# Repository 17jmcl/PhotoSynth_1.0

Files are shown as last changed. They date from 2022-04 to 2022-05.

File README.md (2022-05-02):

# PhotoSynth
 PhotoSynth: A synth using Biodata to modulate effects. 
 
Date Updated Last: 05/02/22

Julie McLaughlin 
Thesis Project for Temple University 
Advisor: Dr. Adam Vidiksis 

Description (What it does, technology used, challenges and future features)
A synth with a 12 note keyboard using Biodata to modulate effects. 

It uses Teensy 3.5, a custom PCB board made with Fusion 360 Autodesk, and Teensyduino IDE. 

How to use the project:
Download SCH,PCB,Gerber, and BOM and open with your preferred developement software (example: Autodesk Fusion 360). Open ino files with Teensyduino or Arduino IDE, adjust your settings, and compile/run the code. 

-------------------------------------------------------------------------------

Dependencies: 
TeensyDuino: PJRC derivative of Arduino 
PJRC Audio Tool: Audio Library (PJRC)
Bounce2: Debouncing library for Arduino 

Credits:
Based on BiodataSonificationBreadboardKit from Sam Cusumano electricityforprogress and Instruo Scion 
Thanks to the help of my family, friends, and collaborators. 

------------------------------------------------------------------------------

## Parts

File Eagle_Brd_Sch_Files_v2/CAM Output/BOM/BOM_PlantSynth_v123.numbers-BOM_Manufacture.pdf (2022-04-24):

### BOM_Manufacture

Qty | Device | Value | Description
1 CPAL-MICRO- | MF-003 | | Power Cable with Button
6 | OEJL-75-2-5 | 3 20mm, 3 7mm (Approx) | Knob Caps
2 Max | Filament | | Choice between PLA, ABS, PETG, PA Nylon, Resin, Nylon Powder
6 Various Reused | Parts | | Parts found from broken electronics
1 | Snap Electrodes | | Pack of snap electrodes to 3.5mm male
1 Snap Electrode | Pads | | Pack of snap electrode pads
10000 | Plants | | Maybe not 10000 but make sure to name them

1

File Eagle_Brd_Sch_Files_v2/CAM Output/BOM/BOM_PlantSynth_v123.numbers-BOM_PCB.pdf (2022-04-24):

### Electronics Design:PlantSynth v123 BOM PCB

Qty | Device | Value | Schematic Labels | Description
2 | 3 Pin Header/ 16mm Knob | 3 pin | R13, R14 | 16mm pot from DHV B10K with B3B-XH-A 3 pin header
7 | B3F Omron Button | 6mm | S1, S2, S3, S4, S5, S6, S7 | OMRON SWITCH
8 | Green LED | Diffused | WP7113SGD1, WP7113SGD2, WP7113SGD3, WP7113SGD4, WP7113SGD5, WP7113SGD6, WP7113SGD7, WP7113SGD8 | WP7113SGD
1 | Capacitor | 0.1uF | C2 | CAPACITOR
1 | Resistor | 100k | R39 | RESISTOR
19 | Resistor | 10k | R1, R2, R3, R10, R11, R12, R15, R16, R17, R18, R19, R20, R21, R22, R23, R24, R25, R26, R40 | RESISTOR
8 | Resistor | 100ohm | R27, R28, R29, R30, R31, R32, R33, R34 | RESISTOR
1 | Capacitor | 4700pF | C1 | CAPACITOR
1 | Polarized Capacitor | 47uF | C3 | Capacitor Polarised
6 | Panasonic Knob | | R4, R5, R6, R7, R8, R9 | 9 mm Square Rotary Potentiometers
12 | FSR | FSR400 Series | FSR1, FSR2, FSR3, FSR4, FSR5, FSR6, FSR7, FSR8, FSR9, FSR10, FSR11, FSR12 | FSR400
1 | 555 Timer | LMC555CN | U3 | LMC555CN/NOPB-ND PDIP(8) TI 9.81x6.35mm
1 | 3.5mm Stereo Jack | Adafruit | STX-3120-5B-577C | STEREO JACK, Adafruit, Breadboard safe
1 | Teensy | Teensy 3.5 | U$1 | PJRC Teensy 3.5
1 | Teensy Audio Hat | SGTL5000 | | PJRC Audio hat (Optional)
1 | Teensy Header Set | 24,24,4 | | Teensy header set

1

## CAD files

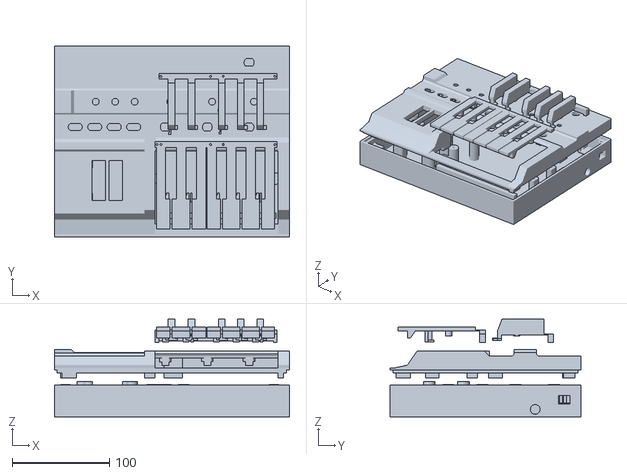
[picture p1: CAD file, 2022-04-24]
Fusion360_3D_Design_Files/Design1/PlantSynth_MainDesign_Full_STL.stl
241.3 x 195.8 x 100.4

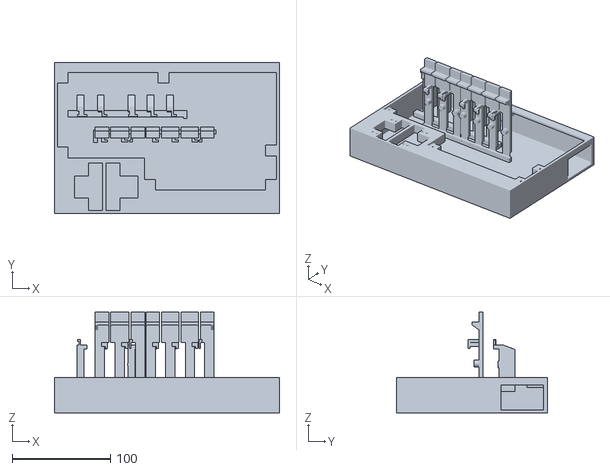
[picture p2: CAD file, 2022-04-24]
Fusion360_3D_Design_Files/Design2/Option2_Full_STL.stl
229.6 x 154.1 x 102.8

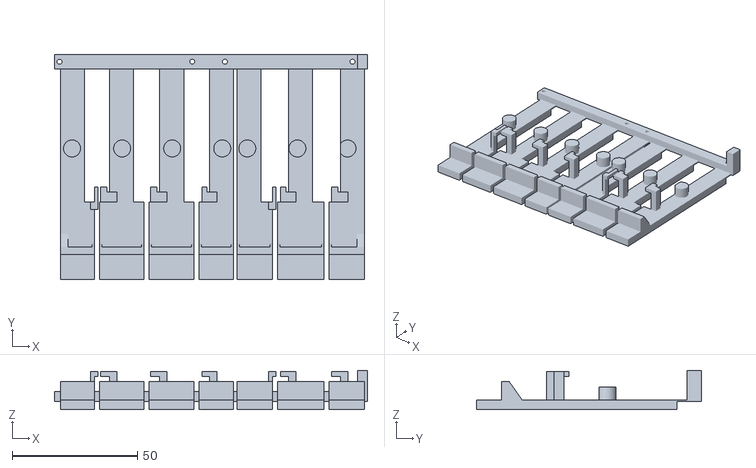
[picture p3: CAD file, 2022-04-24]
Fusion360_3D_Design_Files/Design1/3D_Export_Other/White Piano Keys_STL.stl
125.0 x 89.9 x 15.7

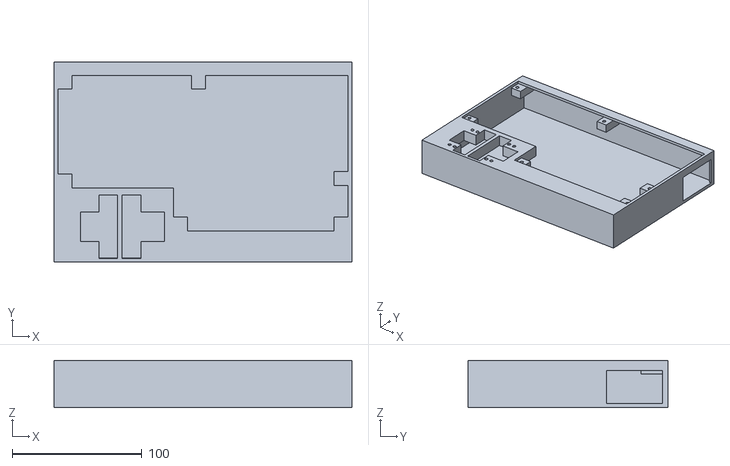
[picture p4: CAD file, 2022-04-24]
Fusion360_3D_Design_Files/Design2/Options2_3D_Export_Other/Option2_BODYonly_STL.stl
229.6 x 154.1 x 36.2

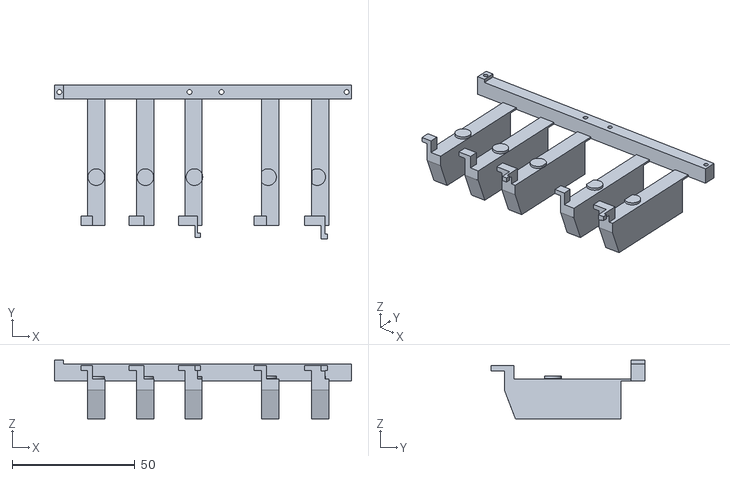
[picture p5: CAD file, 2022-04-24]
Fusion360_3D_Design_Files/Design1/3D_Export_Other/BlackKeys_STL.stl
121.0 x 62.7 x 23.9

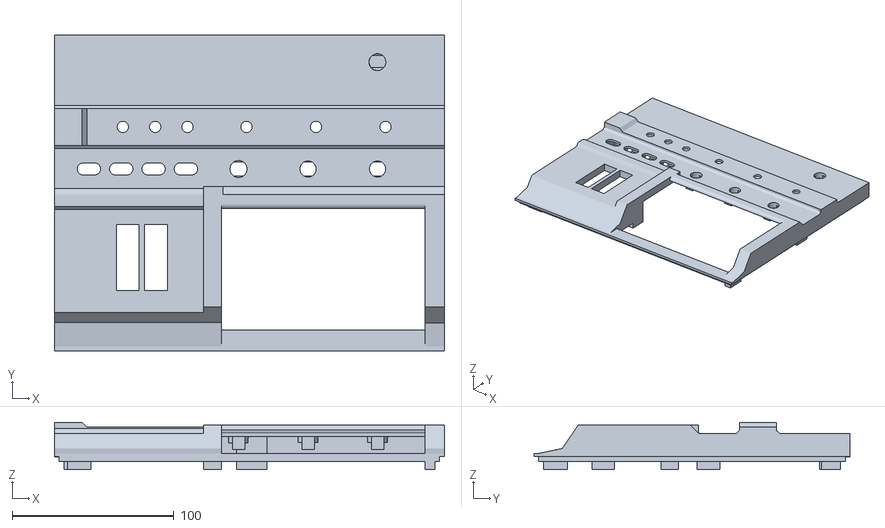
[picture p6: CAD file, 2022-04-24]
Fusion360_3D_Design_Files/Design1/3D_Export_Other/TopOnly_STL.stl
241.3 x 195.8 x 29.2

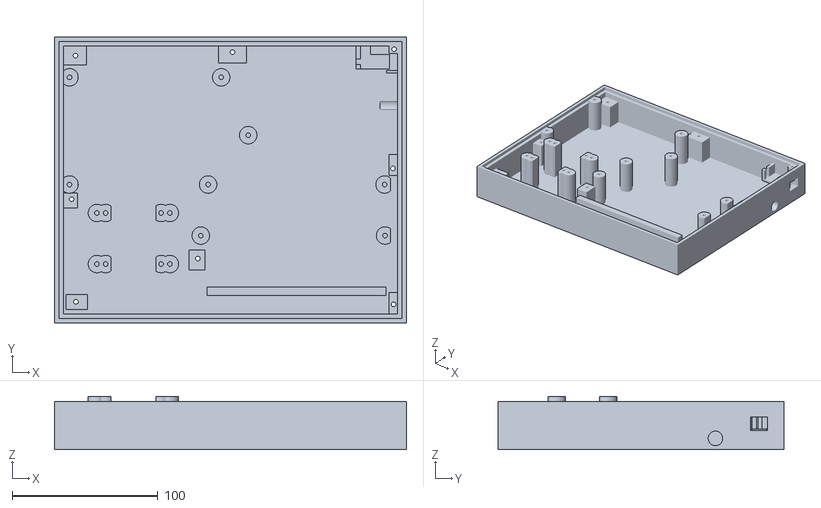
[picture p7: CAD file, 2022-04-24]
Fusion360_3D_Design_Files/Design1/3D_Export_Other/BottomOnly_STL.stl
241.3 x 195.8 x 36.5

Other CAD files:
Fusion360_3D_Design_Files/Design1/3D_Export_Other/PlantSynth_MainDesign_3MF.3mf
Fusion360_3D_Design_Files/Design1/3D_Export_Other/PlantSynth_MainDesign_OBJ.obj
Fusion360_3D_Design_Files/Design2/Options2_3D_Export_Other/Option2_ASCII.stl
Fusion360_3D_Design_Files/Design2/Options2_3D_Export_Other/Option2_3MF.3mf
Fusion360_3D_Design_Files/Design2/Options2_3D_Export_Other/Option2_OBJ.obj
Eagle_Brd_Sch_Files_v2/Electronics Design_PlantSynth_v131.f3z

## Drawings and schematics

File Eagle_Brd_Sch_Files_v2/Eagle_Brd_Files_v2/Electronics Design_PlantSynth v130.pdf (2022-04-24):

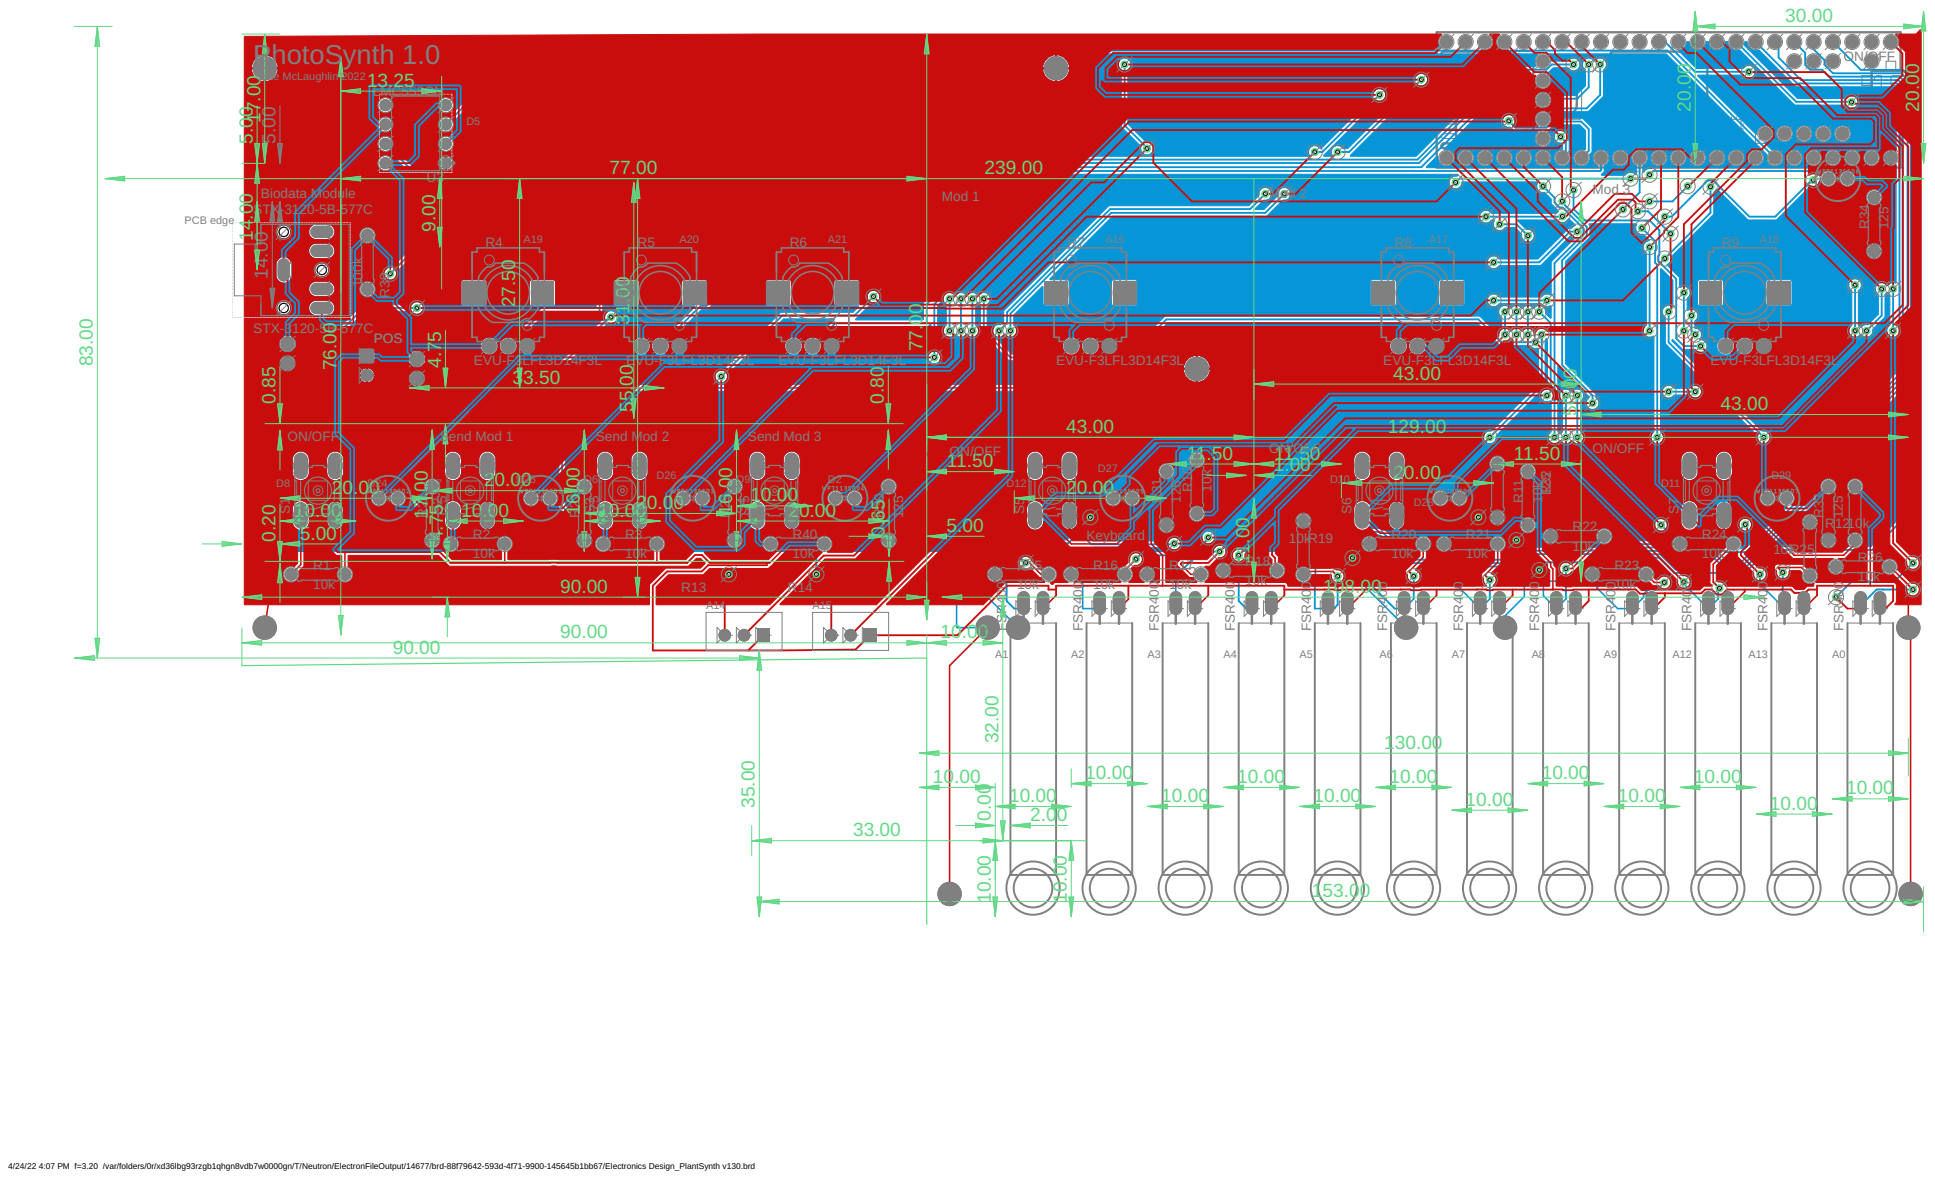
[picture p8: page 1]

4/24/22 4:07 PM f=3.20 /var/folders/0r/xd36lbg93rzgb1qhgn8vdb7w0000gn/T/Neutron/ElectronFileOutput/14677/brd-88f79642-593d-4f71-9900-145645b1bb67/Electronics Design_PlantSynth v130.brd

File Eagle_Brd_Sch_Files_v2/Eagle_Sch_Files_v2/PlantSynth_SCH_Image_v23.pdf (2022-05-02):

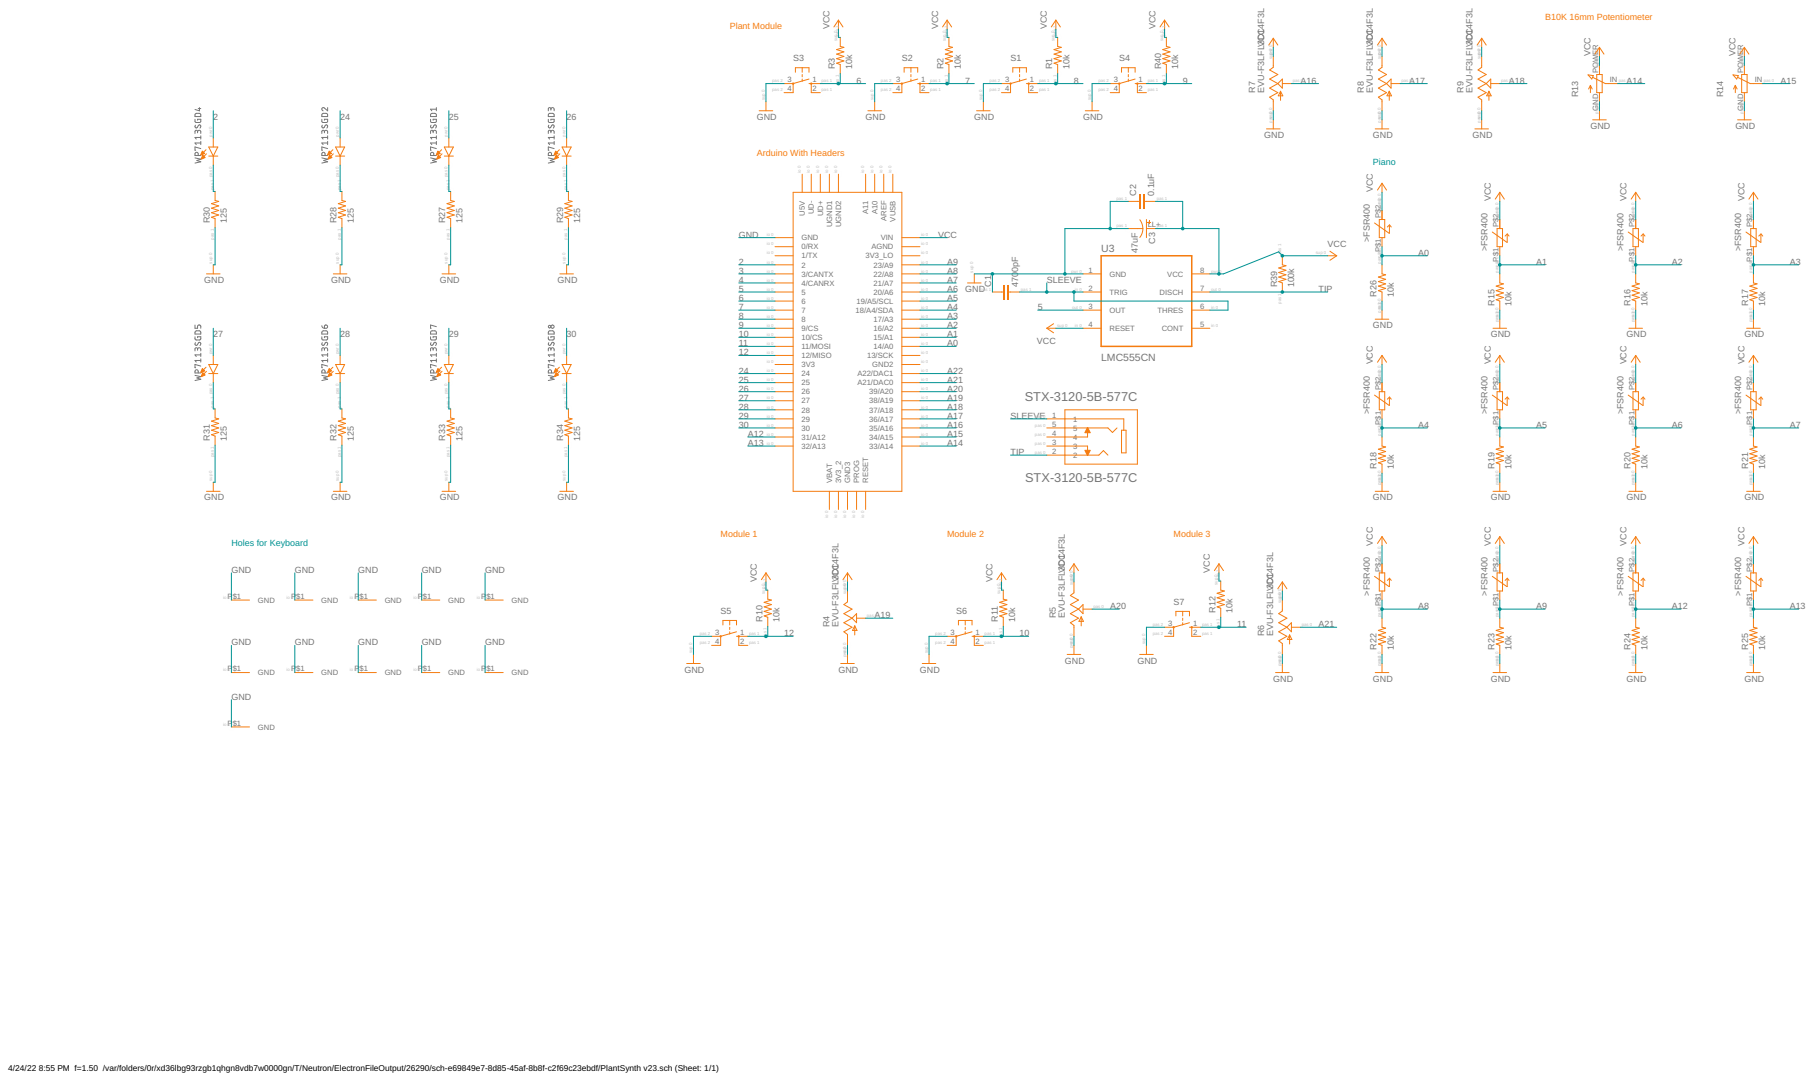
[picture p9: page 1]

pas 1 pas 1 out 0 pwr 0 sup 0 sup 0

out 0 pwr 0 sup 0 sup 0

4/24/22 8:55 PM f=1.50 /var/folders/0r/xd36lbg93rzgb1qhgn8vdb7w0000gn/T/Neutron/ElectronFileOutput/26290/sch-e69849e7-8d85-45af-8b8f-c2f69c23ebdf/PlantSynth v23.sch (Sheet: 1/1)

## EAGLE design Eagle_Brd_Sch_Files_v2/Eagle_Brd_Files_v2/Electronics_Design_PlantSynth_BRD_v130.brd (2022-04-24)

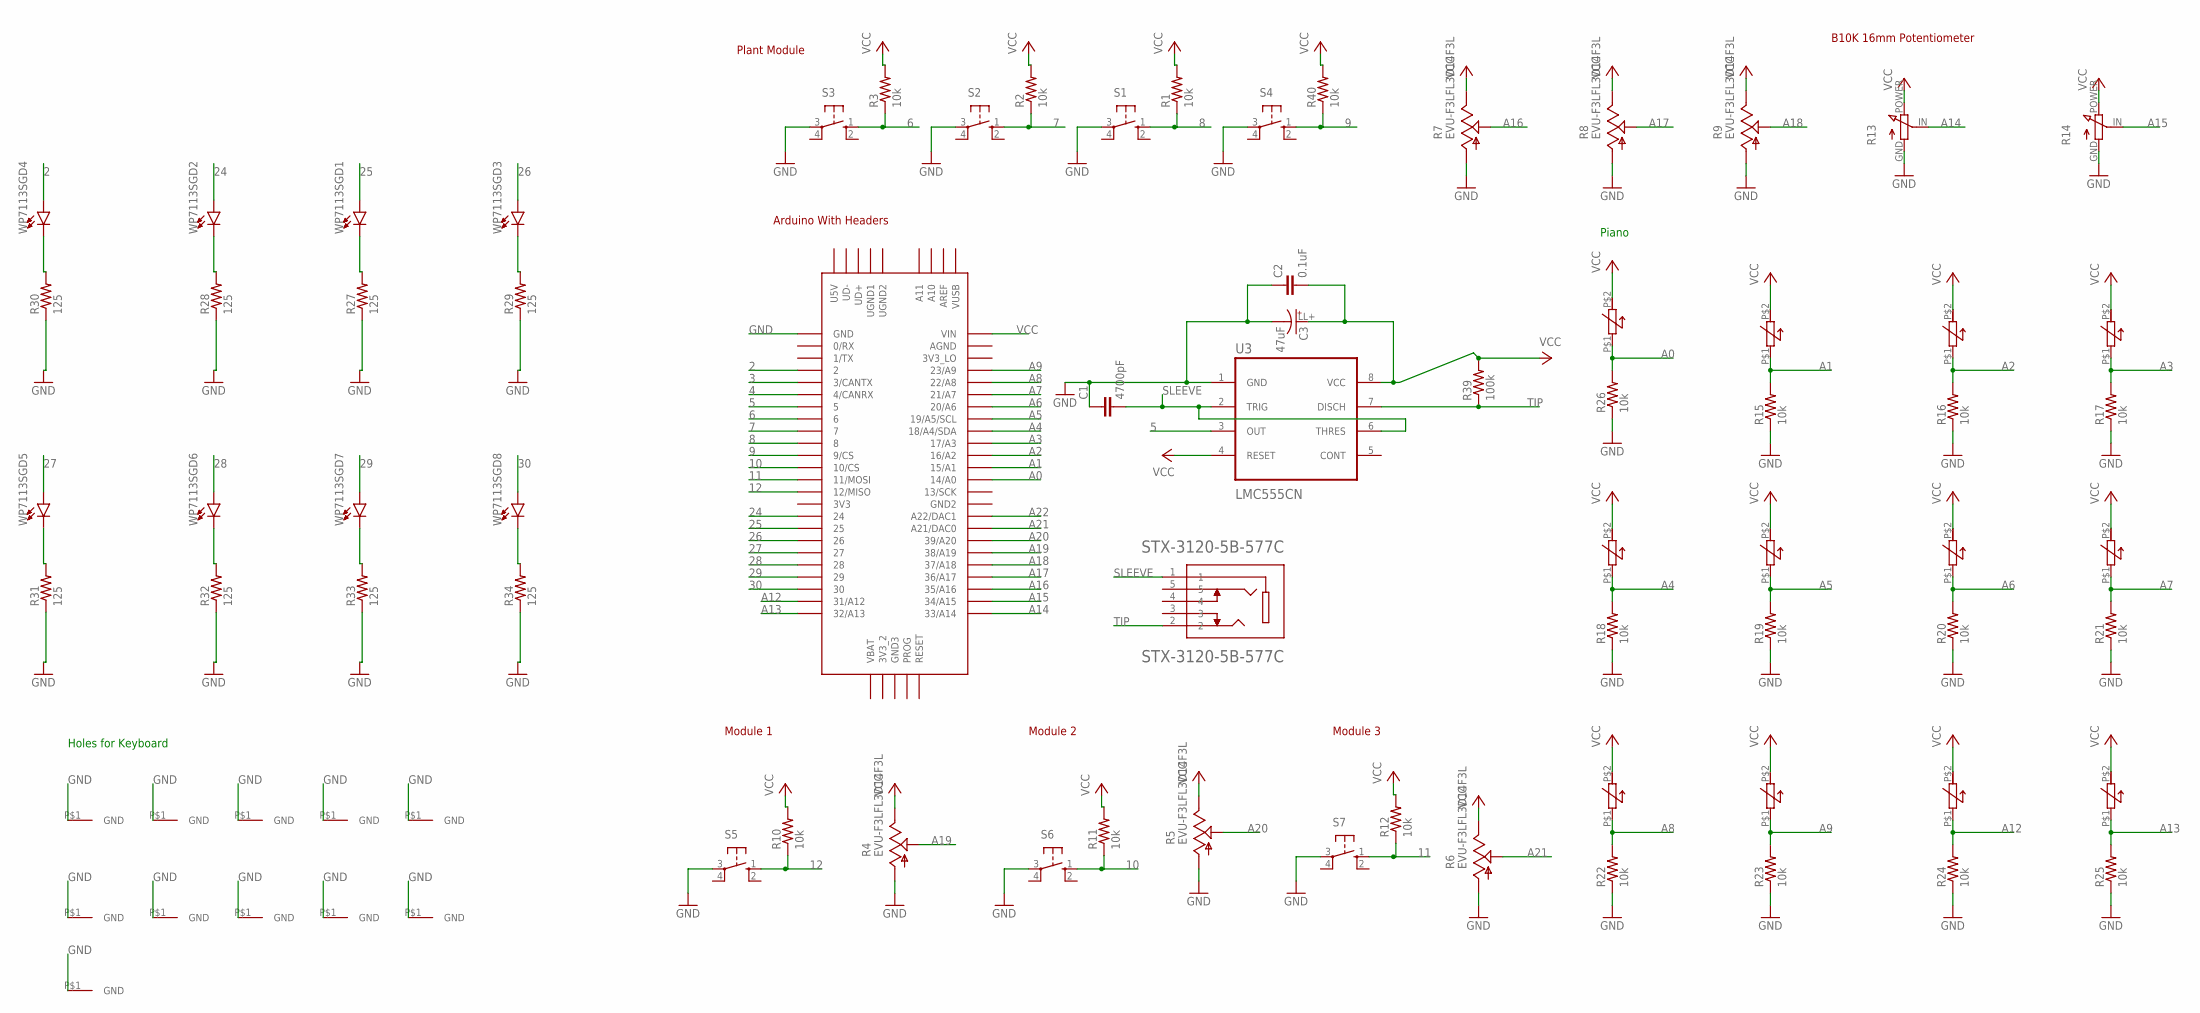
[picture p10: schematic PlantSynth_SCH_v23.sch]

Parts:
C1: 4700pF; C2.5-2
C2: 0.1uF; C2.5-2
C3: 47uF; ESK476M050AE3EA_47UF_CAP
FSR1, FSR2, FSR3, FSR4, FSR5, FSR6, FSR7, FSR8, FSR9, FSR10, FSR11, FSR12: FSR400_0.85; FSR400_.85
GND, GND37, GND38: MOUNTINGHOLE; MOUNTEDHOLE
R1, R2, R3, R10, R11, R12, R15, R16, R17, R18, R19, R20, R21, R22, R23, R24, R25, R26, R40: 10k; 0204/5
R4, R5, R6, R7, R8, R9: EVU-F3LFL3D14F3L; EVUFXL
R13, R14: B3B-XH-AB3B; B3B-XH-A
R27, R28, R29, R30, R31, R32, R33, R34: 125; 0204/5
R39: 100k; 0204/5
S1, S2, S3, S4, S5, S6, S7: B3F-1020; B3F-10XX
STX-3120-5B-577C: STX-3120-5B-577C
U3: LMC555CN; LMC555CN/NOPB-ND
U$1: TEENSY_3.5/3.6
U$2, U$3, U$4, U$5, U$6, U$7, U$8, U$9: MOUNTINGHOLE; MOUNTEDHOLE
WP7113SGD1, WP7113SGD2, WP7113SGD3, WP7113SGD4, WP7113SGD5, WP7113SGD6, WP7113SGD7, WP7113SGD8: LEDGREEN_KINGBRIGHT_WP7113SGD; LEDGREENDIFFUSED5MM

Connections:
2: U$1.2, WP7113SGD4.A+ (ANODE(+))
3: U$1.3/CANTX
4: U$1.4/CANRX
5: U3.3 (OUT), U$1.5
6: R3.1, S3.1 (S), U$1.6
7: R2.1, S2.1 (S), U$1.7
8: R1.1, S1.1 (S), U$1.8
9: R40.1, S4.1 (S), U$1.9/CS
10: R11.1, S6.1 (S), U$1.10/CS
11: R12.1, S7.1 (S), U$1.11/MOSI
12: R10.1, S5.1 (S), U$1.12/MISO
24: U$1.24, WP7113SGD2.A+ (ANODE(+))
25: U$1.25, WP7113SGD1.A+ (ANODE(+))
26: U$1.26, WP7113SGD3.A+ (ANODE(+))
27: U$1.27, WP7113SGD5.A+ (ANODE(+))
28: U$1.28, WP7113SGD6.A+ (ANODE(+))
29: U$1.29, WP7113SGD7.A+ (ANODE(+))
30: U$1.30, WP7113SGD8.A+ (ANODE(+))
A0: FSR12.P$1 (OUT/GND), R26.2, U$1.14/A0
A1: FSR1.P$1 (OUT/GND), R15.2, U$1.15/A1
A2: FSR2.P$1 (OUT/GND), R16.2, U$1.16/A2
A3: FSR3.P$1 (OUT/GND), R17.2, U$1.17/A3
A4: FSR4.P$1 (OUT/GND), R18.2, U$1.18/A4/SDA
A5: FSR5.P$1 (OUT/GND), R19.2, U$1.19/A5/SCL
A6: FSR6.P$1 (OUT/GND), R20.2, U$1.20/A6
A7: FSR7.P$1 (OUT/GND), R21.2, U$1.21/A7
A8: FSR8.P$1 (OUT/GND), R22.2, U$1.22/A8
A9: FSR9.P$1 (OUT/GND), R23.2, U$1.23/A9
A12: FSR10.P$1 (OUT/GND), R24.2, U$1.31/A12
A13: FSR11.P$1 (OUT/GND), R25.2, U$1.32/A13
A14: R13.IN, U$1.33/A14
A15: R14.IN, U$1.34/A15
A16: R7.IN, U$1.35/A16
A17: R8.IN, U$1.36/A17
A18: R9.IN, U$1.37/A18
A19: R4.IN, U$1.38/A19
A20: R5.IN, U$1.39/A20
A21: R6.IN, U$1.21/DAC0 (A21/DAC0)
A22: U$1.A22/DAC1
GND: C1.1, C2.1, C3.LL- (-), GND.P$1, GND37.P$1, GND38.P$1, R4.GND, R5.GND, R6.GND, R7.GND, R8.GND, R9.GND, R13.GND, R14.GND, R15.1, R16.1, R17.1, R18.1, R19.1, R20.1, R21.1, R22.1, R23.1, R24.1, R25.1, R26.1, R27.1, R28.1, R29.1, R30.1, R31.1, R32.1, R33.1, R34.1, S1.3, S2.3, S3.3, S4.3, S5.3, S6.3, S7.3, U3.1 (GND), U$1.GND, U$2.P$1, U$3.P$1, U$4.P$1, U$5.P$1, U$6.P$1, U$7.P$1, U$8.P$1, U$9.P$1
unnamed: R28.2, WP7113SGD2.C- (CATHODE(-))
unnamed: R27.2, WP7113SGD1.C- (CATHODE(-))
unnamed: R29.2, WP7113SGD3.C- (CATHODE(-))
unnamed: R30.2, WP7113SGD4.C- (CATHODE(-))
unnamed: R31.2, WP7113SGD5.C- (CATHODE(-))
unnamed: R32.2, WP7113SGD6.C- (CATHODE(-))
unnamed: R33.2, WP7113SGD7.C- (CATHODE(-))
unnamed: R34.2, WP7113SGD8.C- (CATHODE(-))
SLEEVE: C1.2, STX-3120-5B-577C.1, U3.2 (TRIG), U3.6 (THRES)
TIP: R39.1, STX-3120-5B-577C.2, U3.7 (DISCH)
VCC: C2.2, C3.LL+ (+), FSR1.P$2 (VCC), FSR2.P$2 (VCC), FSR3.P$2 (VCC), FSR4.P$2 (VCC), FSR5.P$2 (VCC), FSR6.P$2 (VCC), FSR7.P$2 (VCC), FSR8.P$2 (VCC), FSR9.P$2 (VCC), FSR10.P$2 (VCC), FSR11.P$2 (VCC), FSR12.P$2 (VCC), R1.2, R2.2, R3.2, R4.PWR (POWER), R5.PWR (POWER), R6.PWR (POWER), R7.PWR (POWER), R8.PWR (POWER), R9.PWR (POWER), R10.2, R11.2, R12.2, R13.POWER, R14.POWER, R39.2, R40.2, U3.4 (RESET), U3.8 (VCC), U$1.VIN

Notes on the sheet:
B10K 16mm Potentiometer
Plant Module
Module 1
Module 2
Module 3
Arduino With Headers
Piano
Holes for Keyboard

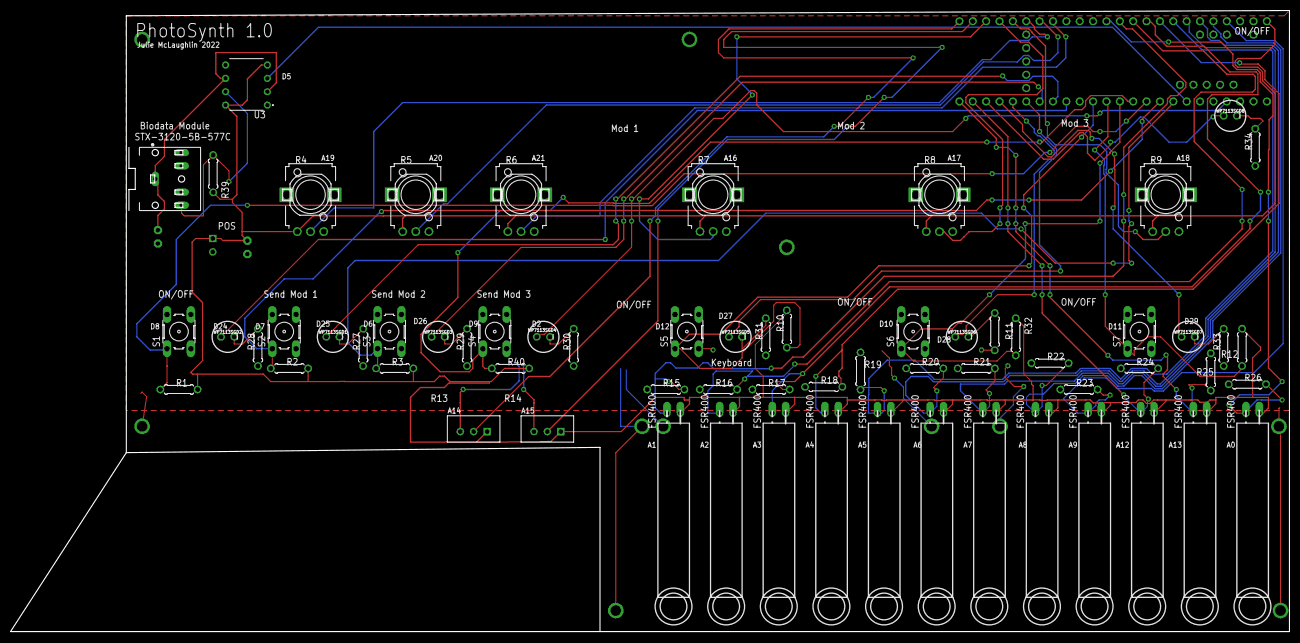
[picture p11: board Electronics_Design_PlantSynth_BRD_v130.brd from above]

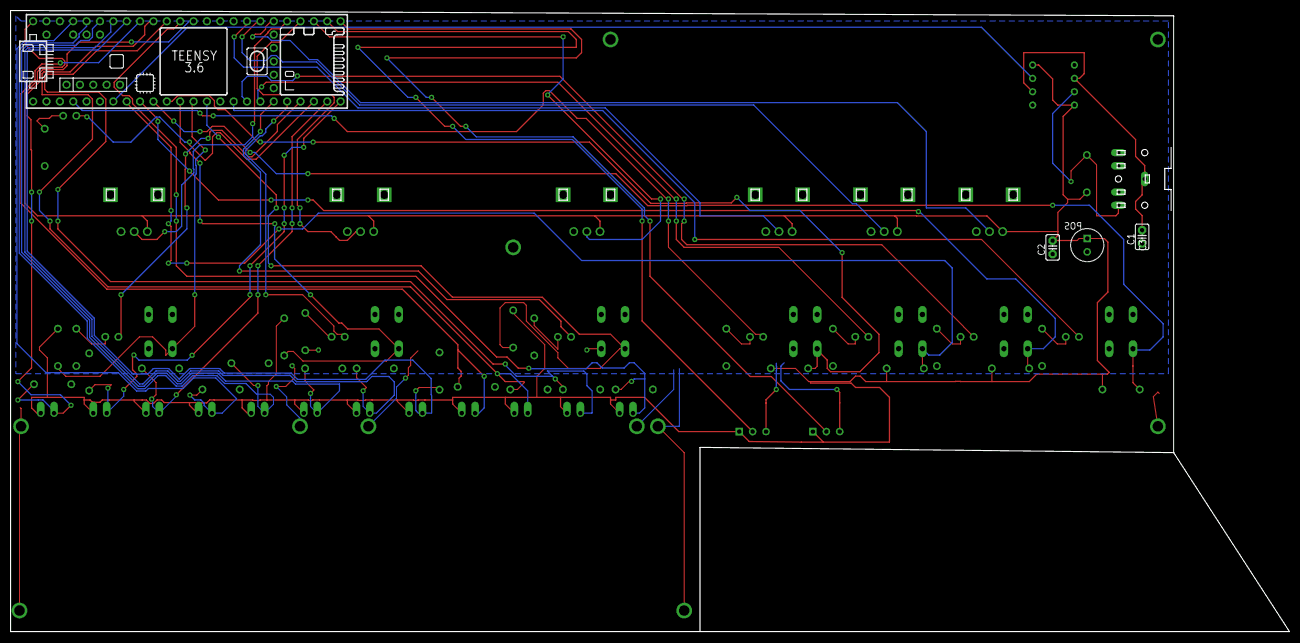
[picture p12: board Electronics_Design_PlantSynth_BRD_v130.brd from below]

Board: 2 copper layers, 243.0 x 118.0 mm, 80 parts (4 on the bottom side), 48 nets.

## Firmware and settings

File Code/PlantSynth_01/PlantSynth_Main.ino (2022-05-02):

void setup() {
  // put your setup code here, to run once:
Serial.begin(9600);
(!Serial);
AudioMemory(20);


//setup sgtl5000_1
sgtl5000_1.enable();
sgtl5000_1.volume(0.5);

//setup main mixers 
mixer3.gain(0,0.9);
waveformMod1.amplitude(0.7);

//setup Piano
PlantSynthKnob newknob; 
newknob.knobSetup(10);

PlantSynthPiano newpiano;
newpiano.pianoSetup();

PlantSynthPlant newplant; 
newplant.plantSetup();


//bitcrush effect setup 
mixer1.gain(0,0.0); 
mixer3.gain(1,0.0); 
button1.attach( BUTTON_PIN2, INPUT );
button1.interval(5); 
button1.setPressedState(LOW); 
pinMode(LED_PIN2,OUTPUT);
digitalWrite(LED_PIN2,ledState);
attachInterrupt((digitalPinToInterrupt(BUTTON_PIN2)), buttonpress, CHANGE);

}

void loop() {

//Piano
playKey();
//Plant Mod (Shape Mod) 
modWave();

//bitcrush effect 
button1.update();
buttonpress();
updatebitcrush();

}

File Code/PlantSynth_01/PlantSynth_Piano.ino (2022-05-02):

#include "Arduino.h" 
#include "PlantSynth_Piano.h"
#include "PlantSynth_AstableMultivibrator.h"

// setup piano sensors 
void PlantSynthPiano::pianoSetup(){
mixGainSetup();
setPianoHz(); 
}

// instantiate all piano key mixer gains to 0.3 
void PlantSynthPiano::mixGainSetup(){
for (int i=0; i<4; i++){
mixer10.gain(i,0.3);
mixer8.gain(i,0.3);
mixer9.gain(i,0.3);
mixer11.gain(i,0.3);
}
};

//set piano keys by Hz 
void PlantSynthPiano::setPianoHz(){
waveformMod1.begin(0.0,493.88,WAVEFORM_PULSE);

waveformMod2.begin(0.0,261.63,WAVEFORM_PULSE);

waveformMod3.begin(0.0,277.18,WAVEFORM_PULSE);

waveformMod4.begin(0.0,293.66,WAVEFORM_PULSE);

waveformMod5.begin(0.0,311.13,WAVEFORM_PULSE);

waveformMod6.begin(0.0,329.63,WAVEFORM_PULSE);

waveformMod7.begin(0.0,349.23,WAVEFORM_PULSE);

waveformMod8.begin(0.0,369.99,WAVEFORM_PULSE);

waveformMod9.begin(0.0,392.00,WAVEFORM_PULSE);

waveformMod10.begin(0.0,415.30,WAVEFORM_PULSE);

waveformMod11.begin(0.0,440,WAVEFORM_PULSE);

waveformMod12.begin(0.0,466.16,WAVEFORM_PULSE);
};

int currWave(){
int knobVal = analogRead(A18);
if (knobVal <= 255 && knobVal >= 0){
return WAVEFORM_SINE; 
}
else if (knobVal <= 510 && knobVal > 255){
return WAVEFORM_SQUARE;
}
else if (knobVal <= 765 && knobVal > 510){
return WAVEFORM_TRIANGLE_VARIABLE;
}
else{
return WAVEFORM_PULSE;
}
}

//playKey 
void playKey(){
int x=0; 
x = currWave();
waveformMod1.begin(x);

waveformMod2.begin(x);

waveformMod3.begin(x);

waveformMod4.begin(x);

waveformMod5.begin(x);

waveformMod6.begin(x);

waveformMod7.begin(x);

waveformMod8.begin(x);

waveformMod9.begin(x);

waveformMod10.begin(x);

waveformMod11.begin(x);

waveformMod12.begin(x);

sensorVal12 = analogRead(sensorPin12);
 if (sensorVal12 > 300){
  waveformMod1.amplitude(0.5);
}
else{
  waveformMod1.amplitude(0.0);
}

sensorVal1 = analogRead(sensorPin1);
 if (sensorVal1 > 500){

  waveformMod2.amplitude(0.5);
}
else{

  waveformMod2.amplitude(0.0);
}

sensorVal2 = analogRead(sensorPin2);
 if (sensorVal2 > 500){

  waveformMod3.amplitude(0.5);
}
else{

  waveformMod3.amplitude(0.0);
}

sensorVal3 = analogRead(sensorPin3);
 if (sensorVal3 > 500){
 
  waveformMod4.amplitude(0.5);
}
else{

  waveformMod4.amplitude(0.0);
}

sensorVal4 = analogRead(sensorPin4);
 if (sensorVal4 > 860){

  waveformMod5.amplitude(0.5);
}
else{

  waveformMod5.amplitude(0.0);
}

sensorVal5 = analogRead(sensorPin5);
 if (sensorVal5 > 860){
 
  waveformMod6.amplitude(0.5);
}
else{

  waveformMod6.amplitude(0.0);
}

sensorVal6 = analogRead(sensorPin6);
 if (sensorVal6 > 860){

  waveformMod7.amplitude(0.5);
}
else{

  waveformMod7.amplitude(0.0);
}

sensorVal7 = analogRead(sensorPin7);
 if (sensorVal7 > 860){
 
  waveformMod8.amplitude(0.5);
}
else{
 
  waveformMod8.amplitude(0.0);
}
/*
sensorVal8 = analogRead(sensorPin8);
 if (sensorVal8 > 1000){
  waveformMod9.amplitude(0.5);
}
else{
  waveformMod9.amplitude(0.0);
}

sensorVal9 = analogRead(sensorPin9);
 if (sensorVal9 > 1000){
  waveformMod10.amplitude(0.5);
}
else{
  waveformMod10.amplitude(0.0);
}
*/
sensorVal10 = analogRead(sensorPin10);
 if (sensorVal10 > 860){

  waveformMod11.amplitude(0.5);
}
else{

  waveformMod11.amplitude(0.0);
}

sensorVal11 = analogRead(sensorPin11);
 if (sensorVal11 > 860){

  waveformMod12.amplitude(0.5);
}
else{

  waveformMod12.amplitude(0.0);
}
}

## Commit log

2022-04-05 Autodesk and INO_ref Add
    Added Autodesk files and INO reference code
    [Electronics Design_PlantSynth v62.brd, Electronics Design_PlantSynth v63.f3z, PlantSynth_v11.sch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]
2022-04-05 PCBImageAdd
    Added PCB Image
2022-04-06 Added AstableMultivibrator code
    Astable Multivibrator with 100ohm resistors and the 47uF polarized capacitor V5 producing around 80 Hertz (Basis for Plant reading)
2022-04-07 Updated Files
    Update with PCB
2022-04-23 New Files added: Building out whole program
    New Files added: Building out whole program
    [Board DXF.dxf, Electronics Design:PlantSynth v109.csv, Electronics Design:PlantSynth v123.csv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]

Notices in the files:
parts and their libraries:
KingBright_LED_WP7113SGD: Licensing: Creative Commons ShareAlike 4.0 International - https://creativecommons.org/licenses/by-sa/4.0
